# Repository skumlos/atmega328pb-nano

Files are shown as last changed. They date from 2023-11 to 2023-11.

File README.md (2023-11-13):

Arduino Mini Pro clone with Atmega328PB

This is basically an Arduino Mini Pro clone but with an Atmega328PB instead of Atmega328P.

Speed 16MHz and 5V.

The reasoning is to have the secondary I2C controller of the PB version, thus PE0 and PE1
pins are pulled to 2.54mm THT holes just like A4/A5 pins of the primary I2C controller.

Remember to burn a bootloader and fuses with a *real* programmer (like another Arduino
turned into an ISP). This requires you to connect to the ICSP pins, MOSI, MISO, SCK,
RESET, 5V and GND. I used a male pin header row  which I didn't solder but just held in
place during programming.

The design is tested and works, but it is hacked together pretty quick so bugs are possible.

(2023) Martin Hejnfelt, martin@hejnfelt.com

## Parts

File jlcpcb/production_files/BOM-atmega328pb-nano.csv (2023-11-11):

Comment | Designator | Footprint | LCSC
330R | R10 | R_0603_1608Metric | C105881
ATMEGA328PB-AU | U1 | TQFP-32_7x7mm_P0.8mm | C132230
100nF | C10,C12,C13 | C_0603_1608Metric | C14663
RED_LED | D20 | LED_0603_1608Metric | C2286
10K | R11,R20 | R_0603_1608Metric | C25804
SW_SPST | SW1 | SW_Tactile_SPST_NO_Straight_CK_PTS636Sx25SMTRLFS | C2689642
MIC5205-5.0YM5 | U20 | SOT-23-5 | C70431
10uF | C20,C21 | CP_EIA-3216-18_Kemet-A | C7171
GRN_LED | D10 | LED_0603_1608Metric | C72038
CSTNE16M0VH3L000R0 | Y1 | Resonator_SMD_Murata_CSTxExxV-3Pin_3.0x1.1mm | C882605
Conn_01x12_Female | J11 | PinHeader_1x12_P2.54mm_Vertical
Conn_01x06 | J2 | PinHeader_1x06_P2.54mm_Horizontal
Conn_01x12_Female | J10 | PinHeader_1x12_P2.54mm_Vertical
Conn_01x02_Female | J12 | PinHeader_1x02_P2.54mm_Vertical
Conn_01x02_Female | J14 | PinHeader_1x02_P2.54mm_Vertical
Conn_01x02_Female | J13 | PinHeader_1x02_P2.54mm_Vertical
NM | R13 | R_0603_1608Metric
NM | R12 | R_0603_1608Metric

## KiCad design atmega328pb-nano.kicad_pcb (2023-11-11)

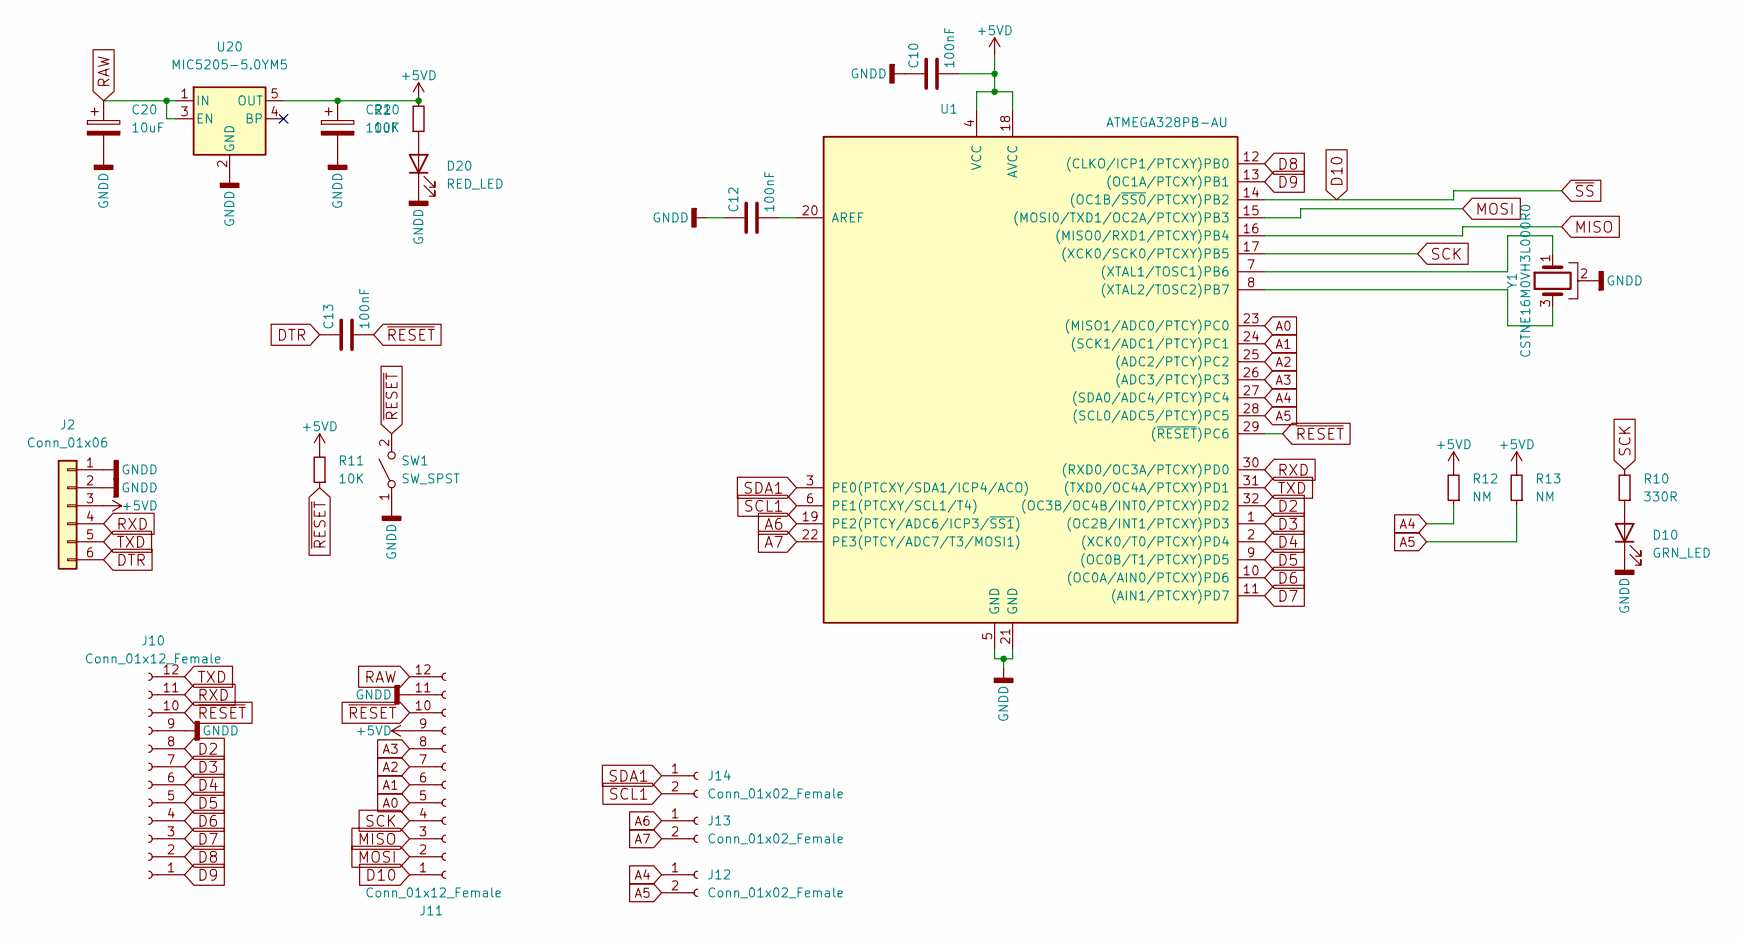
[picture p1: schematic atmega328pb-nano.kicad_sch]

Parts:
C10, C12, C13: 100nF; C_0603_1608Metric
C20, C21: 10uF; CP_EIA-3216-18_Kemet-A
D10: GRN_LED; LED_0603_1608Metric
D20: RED_LED; LED_0603_1608Metric
J2: Conn_01x06; PinHeader_1x06_P2.54mm_Horizontal
J10, J11: Conn_01x12_Female; PinHeader_1x12_P2.54mm_Vertical
J12, J13, J14: Conn_01x02_Female; PinHeader_1x02_P2.54mm_Vertical
R10: 330R; R_0603_1608Metric
R11, R20: 10K; R_0603_1608Metric
R12, R13: NM; R_0603_1608Metric
SW1: SW_SPST; SW_Tactile_SPST_NO_Straight_CK_PTS636Sx25SMTRLFS
U1: ATMEGA328PB-AU; TQFP-32_7x7mm_P0.8mm
U20: MIC5205-5.0YM5; SOT-23-5
Y1: CSTNE16M0VH3L000R0; Resonator_SMD_Murata_CSTxExxV-3Pin_3.0x1.1mm

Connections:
+5VD: C10.2, C21.1, J2.3, J11.9, R11.2, R12.2, R13.2, R20.2, U1.4 (VCC), U1.18 (AVCC), U20.5 (OUT)
A0: J11.5, U1.23 ((MISO1/ADC0/PTCY)PC0)
A1: J11.6, U1.24 ((SCK1/ADC1/PTCY)PC1)
A2: J11.7, U1.25 ((ADC2/PTCY)PC2)
A3: J11.8, U1.26 ((ADC3/PTCY)PC3)
A4: J12.1, R12.1, U1.27 ((SDA0/ADC4/PTCY)PC4)
A5: J12.2, R13.1, U1.28 ((SCL0/ADC5/PTCY)PC5)
A6: J13.1, U1.19 (PE2(PTCY/ADC6/ICP3/~SS1))
A7: J13.2, U1.22 (PE3(PTCY/ADC7/T3/MOSI1))
D2: J10.8, U1.32 ((OC3B/OC4B/INT0/PTCXY)PD2)
D3: J10.7, U1.1 ((OC2B/INT1/PTCXY)PD3)
D4: J10.6, U1.2 ((XCK0/T0/PTCXY)PD4)
D5: J10.5, U1.9 ((OC0B/T1/PTCXY)PD5)
D6: J10.4, U1.10 ((OC0A/AIN0/PTCXY)PD6)
D7: J10.3, U1.11 ((AIN1/PTCXY)PD7)
D8: J10.2, U1.12 ((CLKO/ICP1/PTCXY)PB0)
D9: J10.1, U1.13 ((OC1A/PTCXY)PB1)
D10: J11.1, U1.14 ((OC1B/~SS0/PTCXY)PB2)
DTR: C13.1, J2.6
GNDD: C10.1, C12.1, C20.2, C21.2, D10.1 (K), D20.1 (K), J2.1, J2.2, J10.9, J11.11, SW1.1 (A), U1.5 (GND), U1.21 (GND), U20.2 (GND), Y1.2
MISO: J11.3, U1.16 ((MISO0/RXD1/PTCXY)PB4)
MOSI: J11.2, U1.15 ((MOSI0/TXD1/OC2A/PTCXY)PB3)
unnamed: C12.2, U1.20 (AREF)
unnamed: D10.2 (A), R10.1
unnamed: D20.2 (A), R20.1
unnamed: U1.7 ((XTAL1/TOSC1)PB6), Y1.1
unnamed: U1.8 ((XTAL2/TOSC2)PB7), Y1.3
RAW: C20.1, J11.12, U20.1 (IN), U20.3 (EN)
RXD: J2.4, J10.11, U1.30 ((RXD0/OC3A/PTCXY)PD0)
SCK: J11.4, R10.2, U1.17 ((XCK0/SCK0/PTCXY)PB5)
SCL1: J14.2, U1.6 (PE1(PTCXY/SCL1/T4))
SDA1: J14.1, U1.3 (PE0(PTCXY/SDA1/ICP4/ACO))
TXD: J2.5, J10.12, U1.31 ((TXD0/OC4A/PTCXY)PD1)
~RESET: C13.2, J10.10, J11.10, R11.1, SW1.2 (B), U1.29 ((~RESET)PC6)

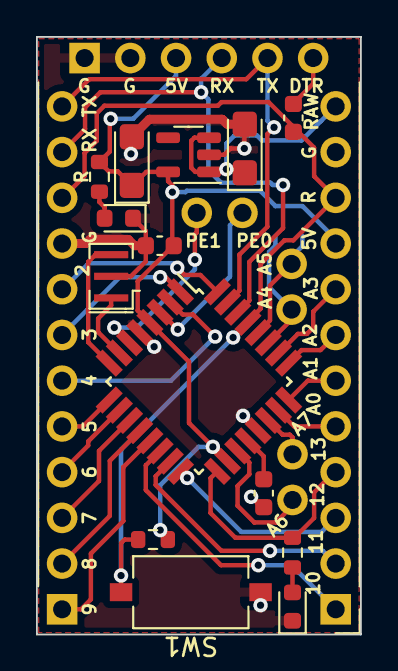
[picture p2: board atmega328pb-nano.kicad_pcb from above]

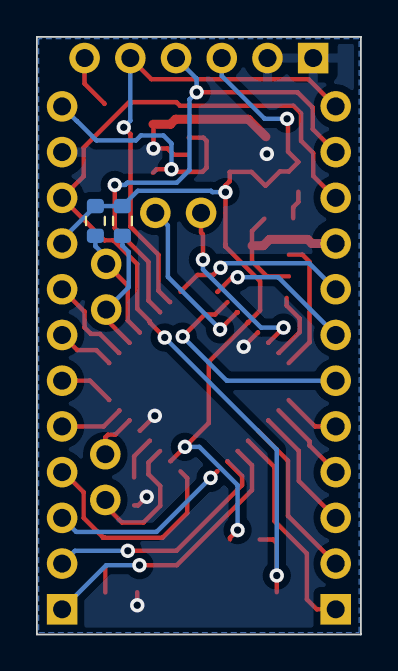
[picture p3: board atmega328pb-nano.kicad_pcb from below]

Board: 2 copper layers, 18.0 x 33.2 mm, 22 parts (2 on the bottom side), 34 nets.
